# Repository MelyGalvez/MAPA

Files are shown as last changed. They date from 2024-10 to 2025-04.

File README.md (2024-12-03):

# MAPA
Module d'Apprentissage du Piano Automatisé (MAPA)

# Table des matières
1. Equipe de travail
2. Description du projet
3. Journal de bord

# 1. Equipe de travail

Software: Mely & Marin

Hardware: Justine & Jiajing

# 2. Description du projet
# 3. Journal de bord

## Première session 17 septembre 2024

Mise en place du projet MAPA. Brainstorming sur les différents point du sujet MAPA. Conception du diagramme fonctionnel du projet.

<div align="center">
  Schéma des étapes du projet
</div>
<div align="center">
Schéma des étapes du projet
</div>

<div align="center">
  Diagramme fonctionnel primitif
</div>
<div align="center">
Diagramme fonctionnel primitif
</div>

## Deuxième session 24 septembre 2024
Software: début de recherche de code pour traiter un fichier MIDI grâce à la STM32. Aussi recherche de code pour traiter un fichier audio (.wav)

Hardware: recherche des références des composants
## Troisième session 01 octobre 2024
Software: Avancement et réglage des erreurs du code de la semaine dernière

Hardware: Listes des références presque fini pour commander. Emprunt d'une petite bande LED à Mme.Kittel pour tester un code

## Quatrième session 8 octobre 2024

Présentation de l'avancement du projet

Software: Tuto en cours de compréhension, bibliothèque CMSIS installé. Code de control de Led avancé

Hardware: phase final des listes de références, régulateur, ruban led. Classification des composants dans des excels différent selon les contructeur pour commander

## Cinquième session 22 octobre 2024


## Sixième session 05 novembre 2024
Chez pas
## Septième session 12 novembre 2024

Code pour l'initialisation du ruban led avec 3 boutons

## Huitième session 19 novembre 2024

Mesure des touches du piano pour connaitre le ruban led ou  matrice de led à prendre

## Neuvième session 26 novembre 2024

Décision finale pour le choix de ruban led 

## Dixième session 03 décembre 2024
Mise en forme

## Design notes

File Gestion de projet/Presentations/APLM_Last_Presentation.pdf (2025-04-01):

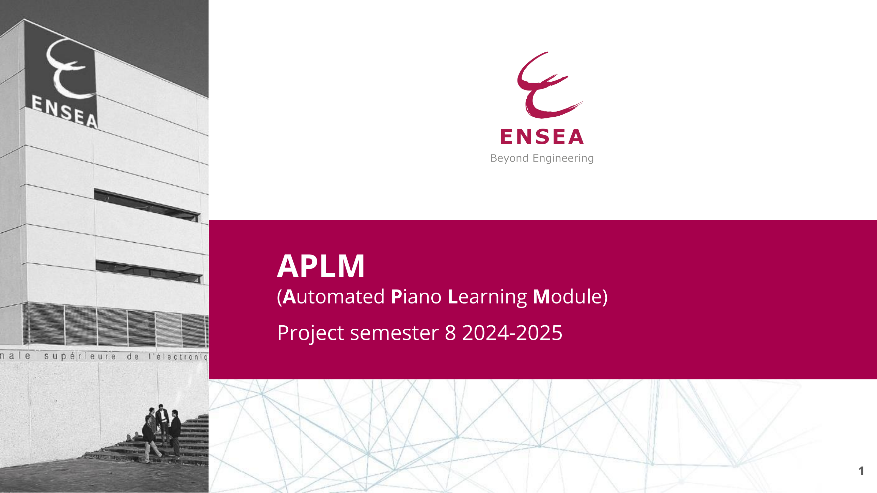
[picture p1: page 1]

# APLM

## (Automated Piano Learning Module)

## Project semester 8 2024-2025

1

# Contents

# I. Reminder and brief presentation of the project

# II. Demonstration

# III. Additional schematic and PCB Design

# IV. Digital audio signal processing

2

## I. Reminder and brief presentation of the project

# I. Reminder and brief presentation of the project

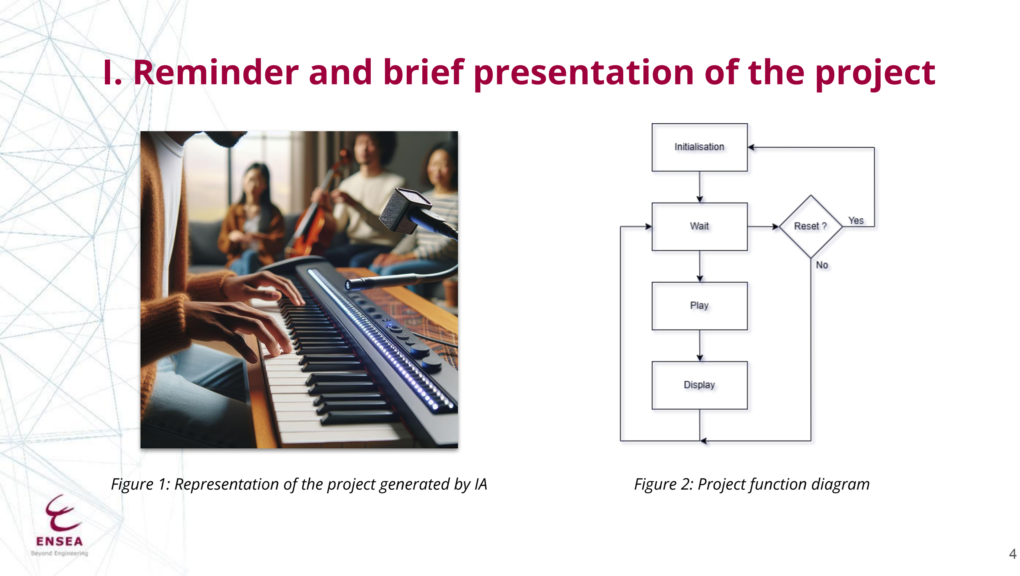
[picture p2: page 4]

Figure 1: Representation of the project generated by IA

Figure 2: Project function diagram

# I. Reminder and brief presentation of the project

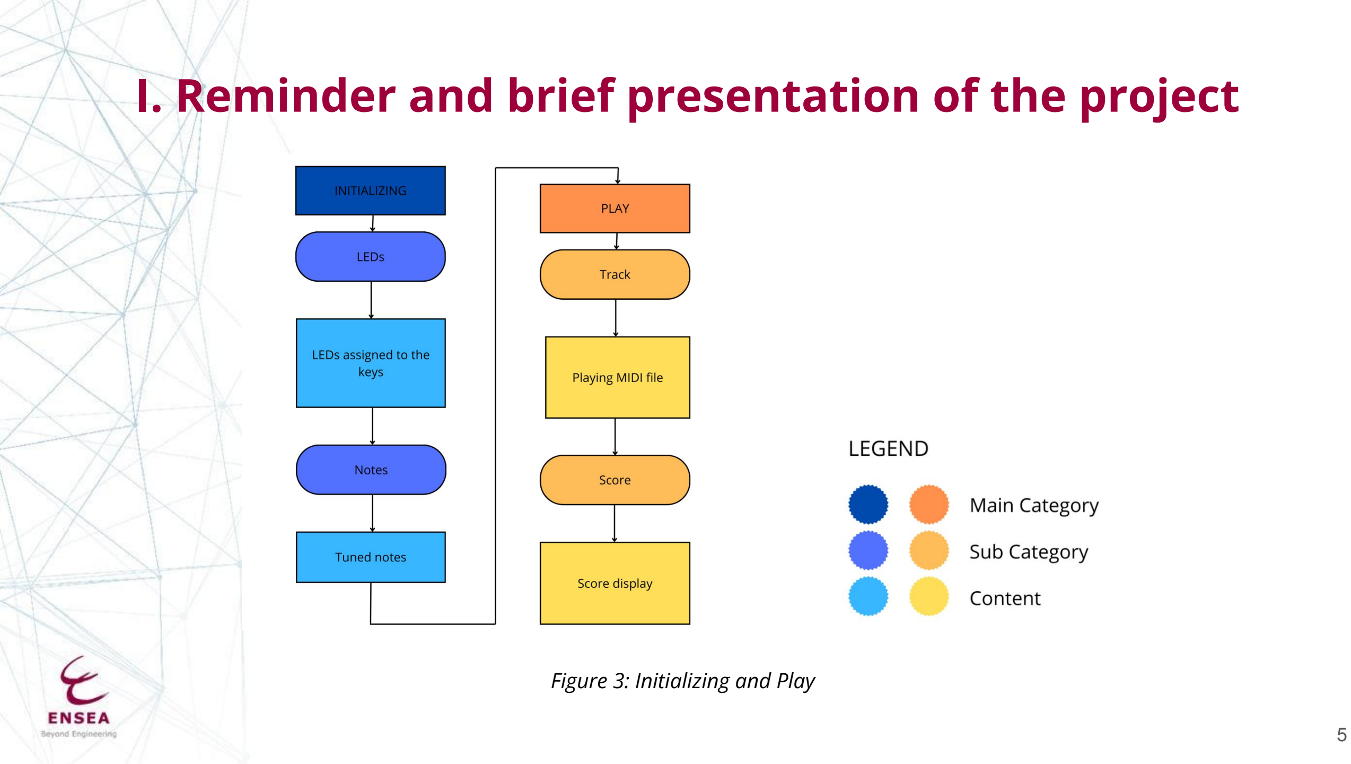
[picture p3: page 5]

Figure 3: Initializing and Play

## II. Demonstration

# II. Demonstration

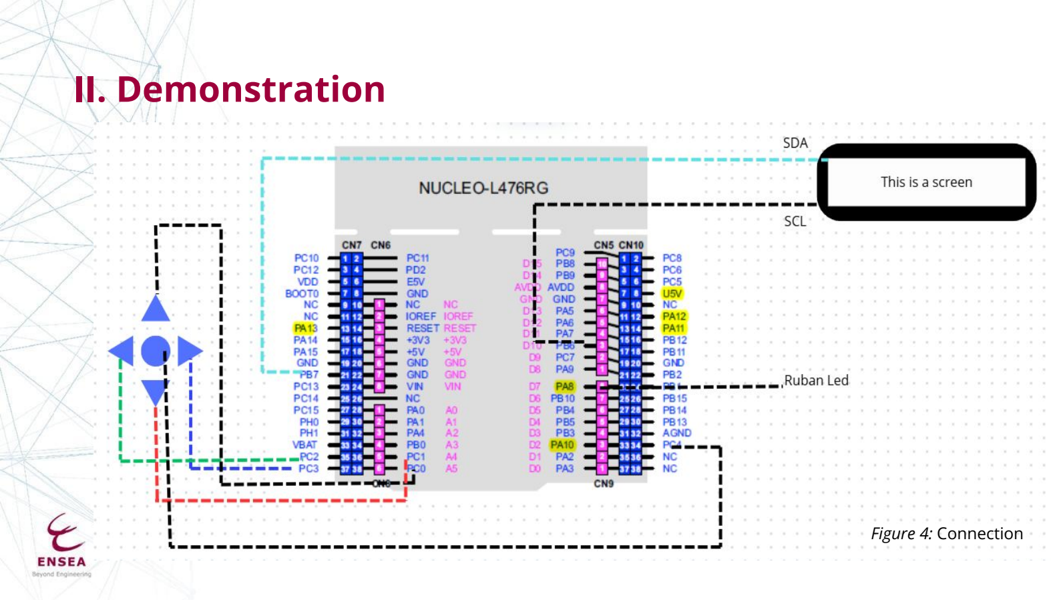
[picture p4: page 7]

Figure 4: Connection

# 1) Initialization

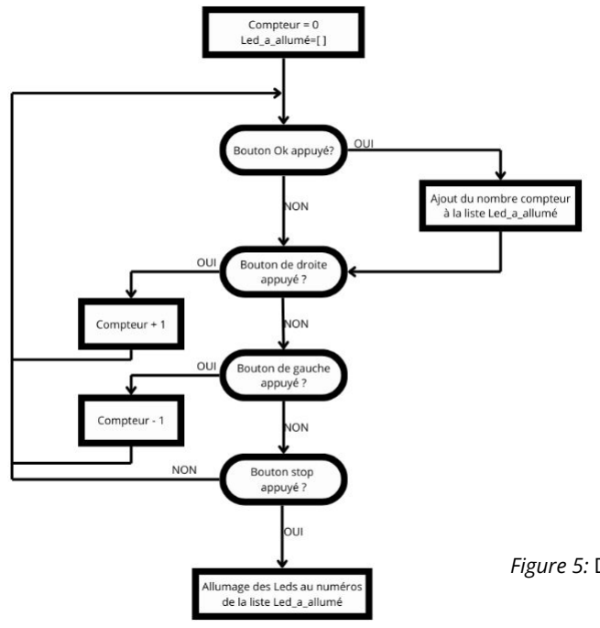
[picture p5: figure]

Figure 5: Decision diagram of Led assign

# 2) Menu

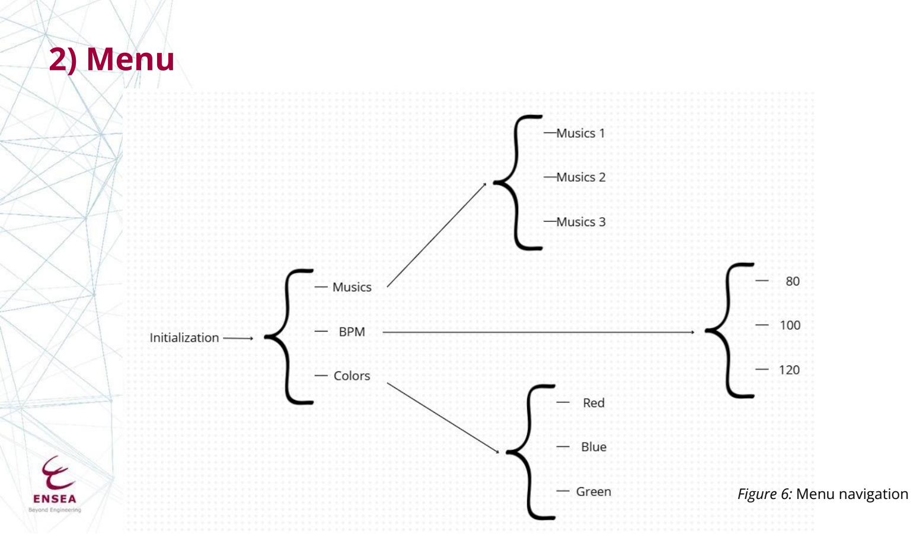
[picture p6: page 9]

Figure 6: Menu navigation

# 3) Possible Ameliorations

- Do the test for an entire piano and not just an octave
- Store more MIDI file in a SD card to play different music
- Increase the number of floors
- Complete the User Interface and functionality (Colors,BPM,...)
- Correct the initialization list with the real list played when there are several floors

## III. Additional schematic and PCB Design

# III. Additional schematic and PCB Design

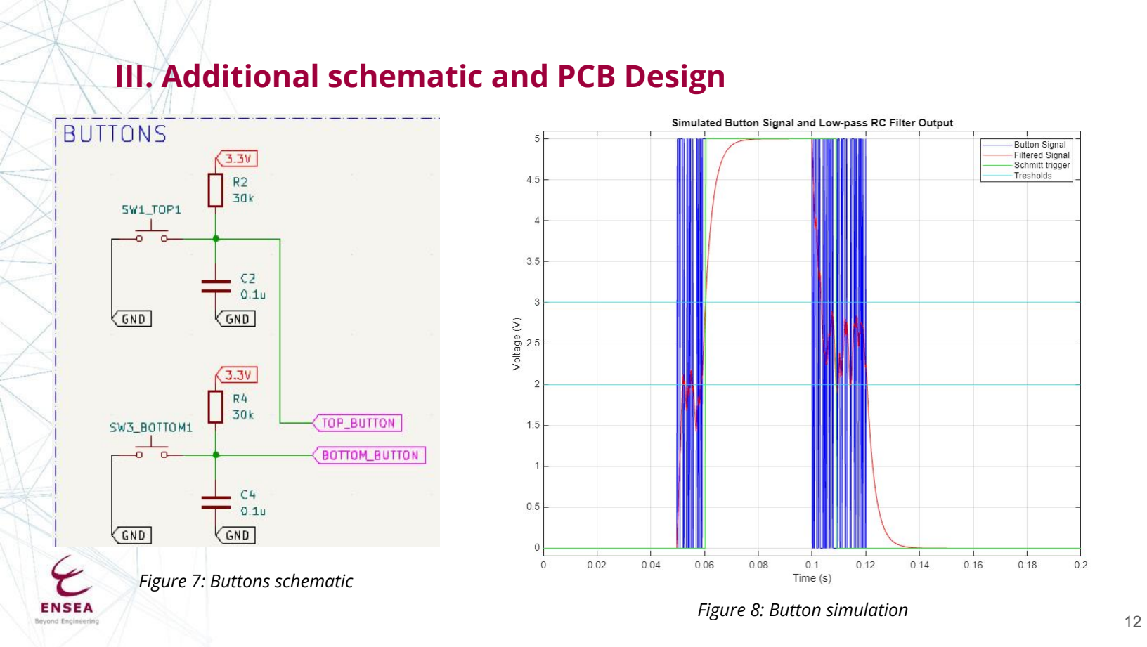
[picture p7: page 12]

Figure 7: Buttons schematic Figure 8: Button simulation

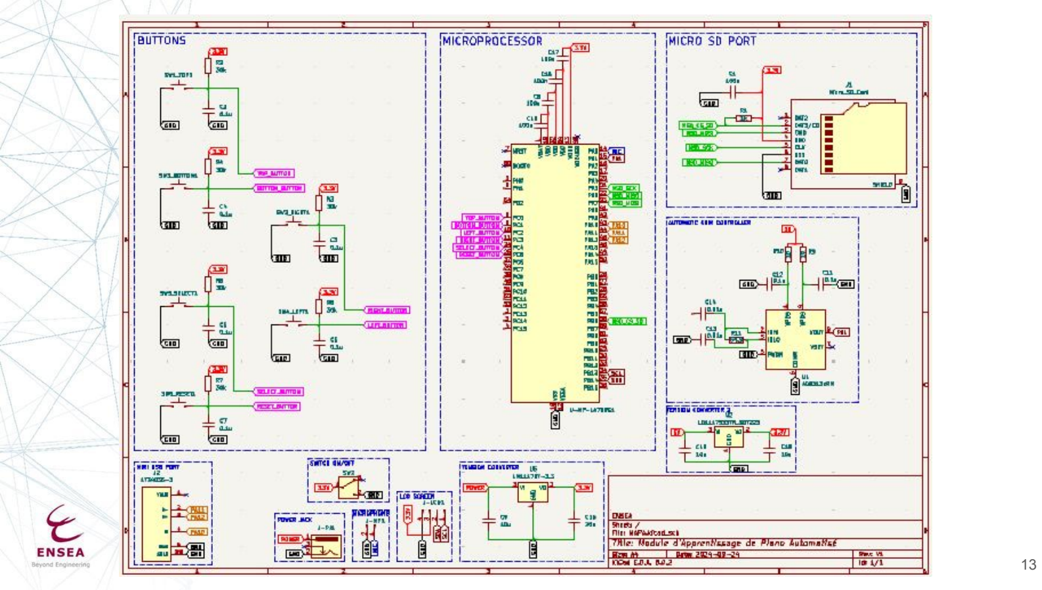
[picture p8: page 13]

# III. Additional schematic and PCB Design

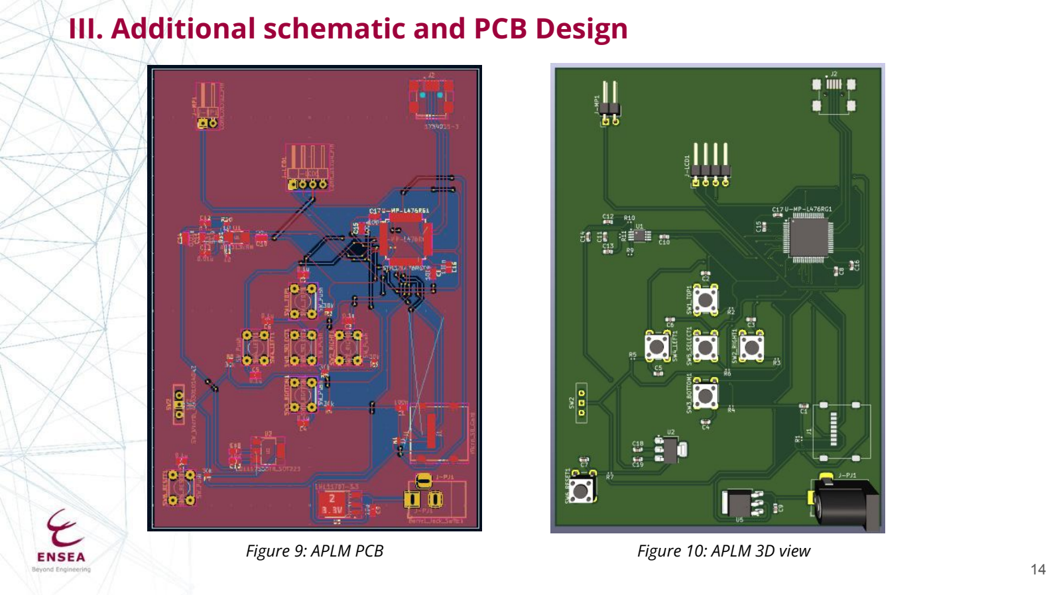
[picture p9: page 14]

Figure 9: APLM PCB

Figure 10: APLM 3D view

# III. Additional schematic and PCB Design

What's left to do as of today :

- Fix the issue with certain components on the PCB
- Print the PCB
- Solder the components onto the board

## IV. Digital audio signal processing

# IV. Digital audio signal processing

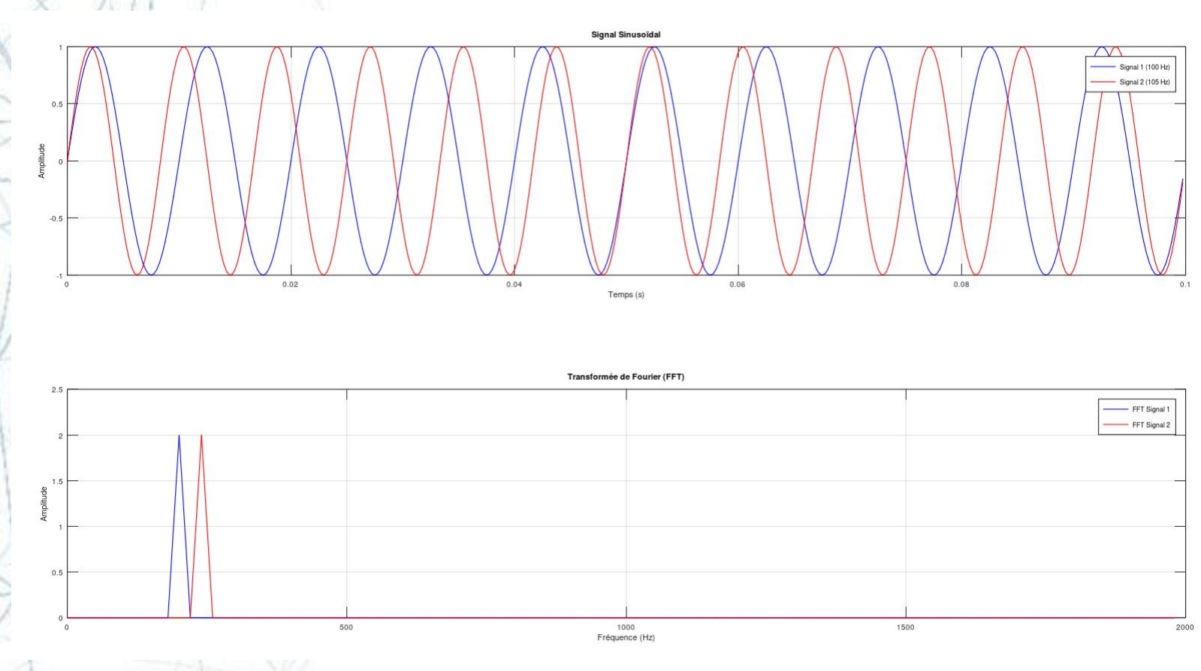
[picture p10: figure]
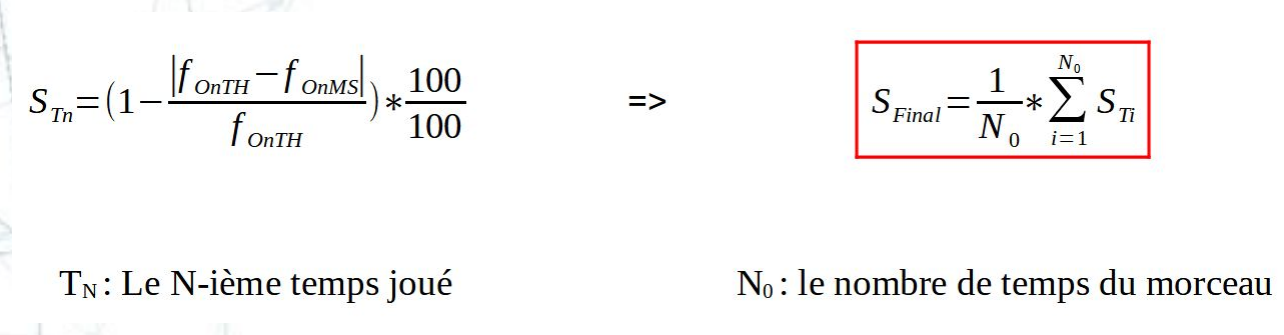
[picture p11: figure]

Figure 11: Method for evaluating the user score

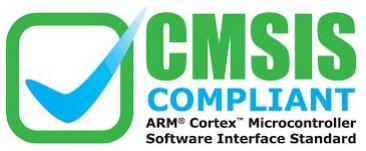
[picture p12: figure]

Figure 12: Useful libraries for the project

# V. Digital audio signal processing

# Solutions

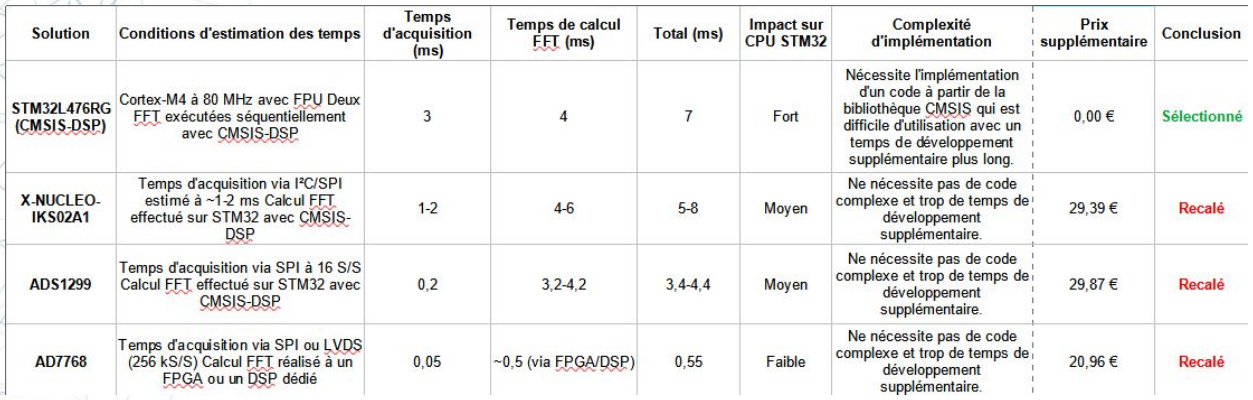
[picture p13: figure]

Figure 13: Options in numbers

# V. Digital audio signal processing

# Paradigm shift

# When initialising, record every FFT of every note on the piano!

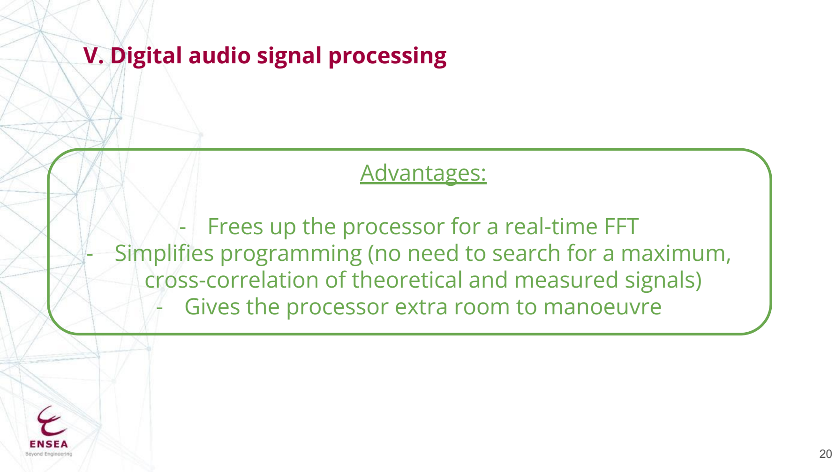
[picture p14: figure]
V. Digital audio signal processing; Advantages:

# - Frees up the processor for a real-time FFT

- Simplifies programming (no need to search for a maximum,

# cross-correlation of theoretical and measured signals) - Gives the processor extra room to manoeuvre

# V. Digital audio signal processing

# Physical simulation of the new process

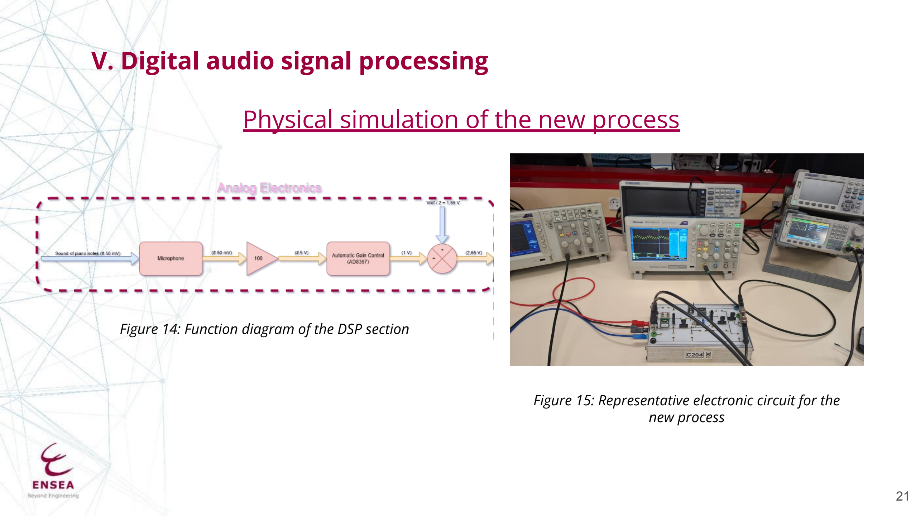
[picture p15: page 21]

Figure 15: Representative electronic circuit for the new process

Figure 14: Function diagram of the DSP section

# V. Digital audio signal processing

# Physical simulation of the new process

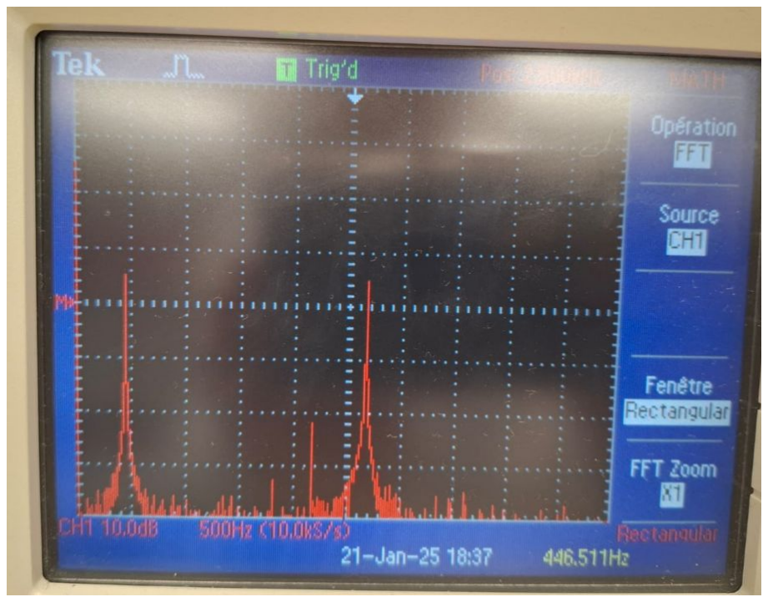
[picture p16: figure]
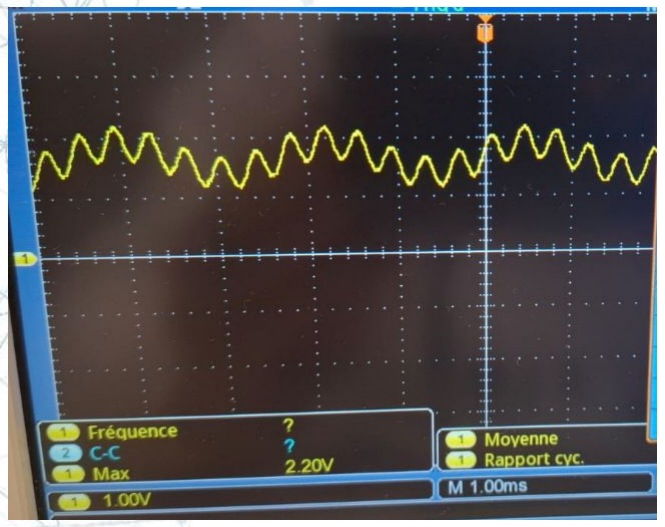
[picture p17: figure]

Figure 17: FFT of the sum Figure 16: Sum of signals

# V. Digital audio signal processing

# Introduction of white noise

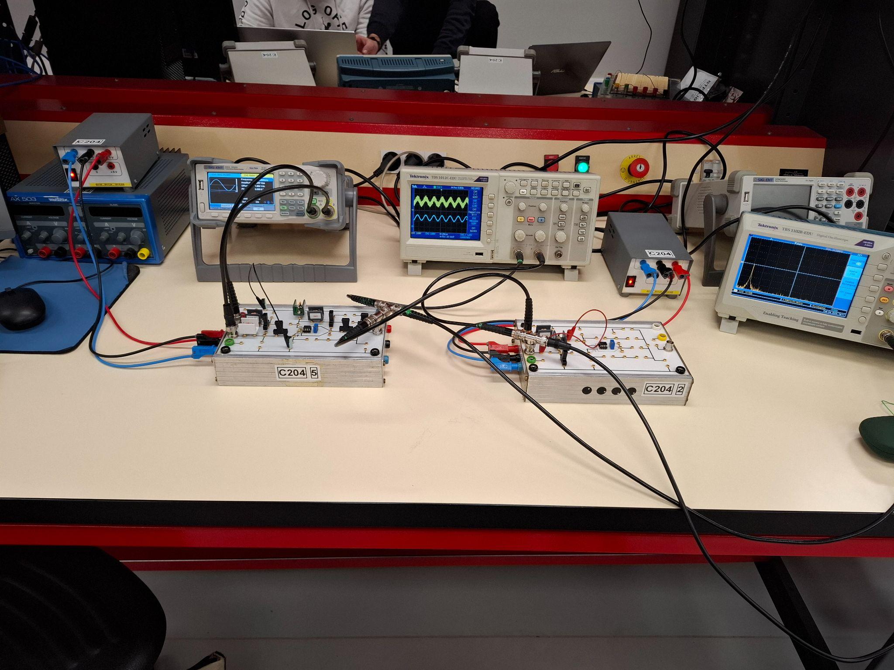
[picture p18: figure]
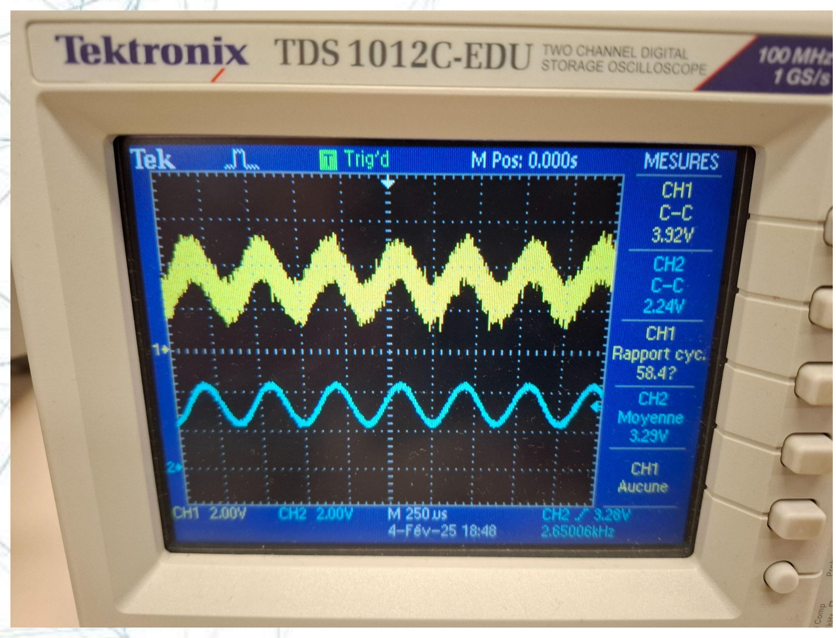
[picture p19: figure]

Figure 19: Electrical installation Figure 18: Noisy and filtered signal

# V. Digital audio signal processing

# Averaging filter

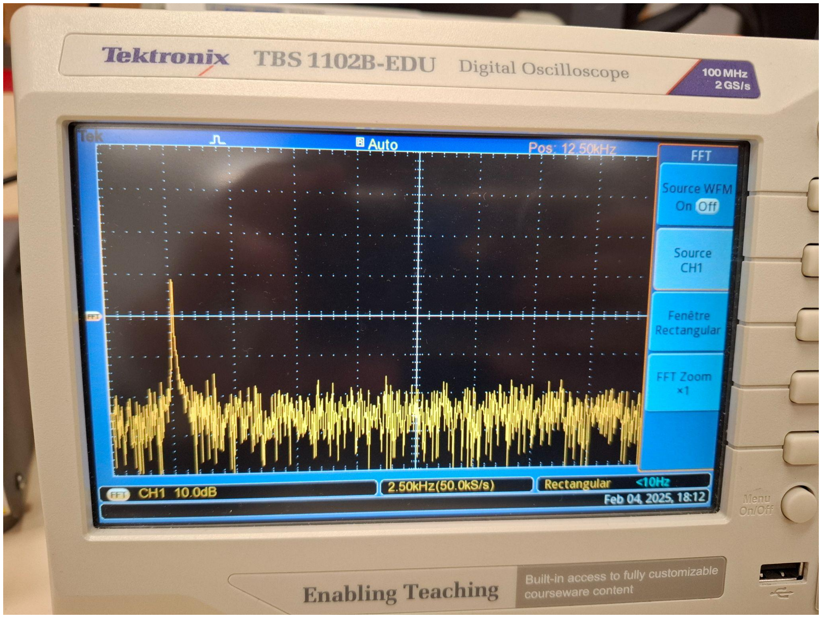
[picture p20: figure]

Figure 20: Filtered FFT

# V. Digital audio signal processing

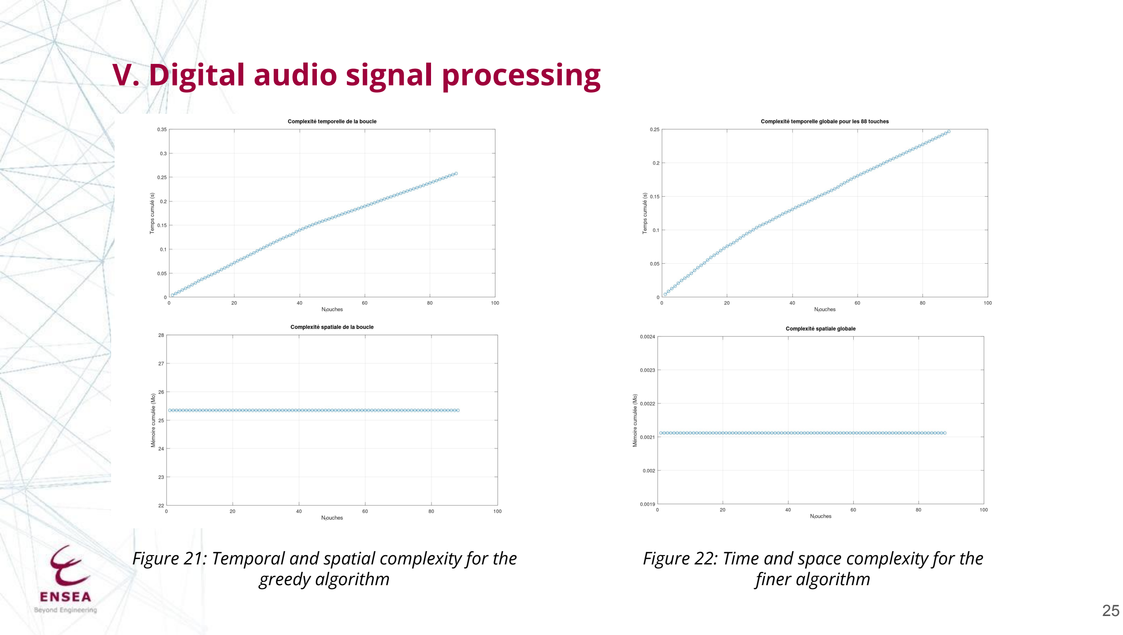
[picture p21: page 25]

Figure 22: Time and space complexity for the finer algorithm

Figure 21: Temporal and spatial complexity for the greedy algorithm

# V. Digital audio signal processing

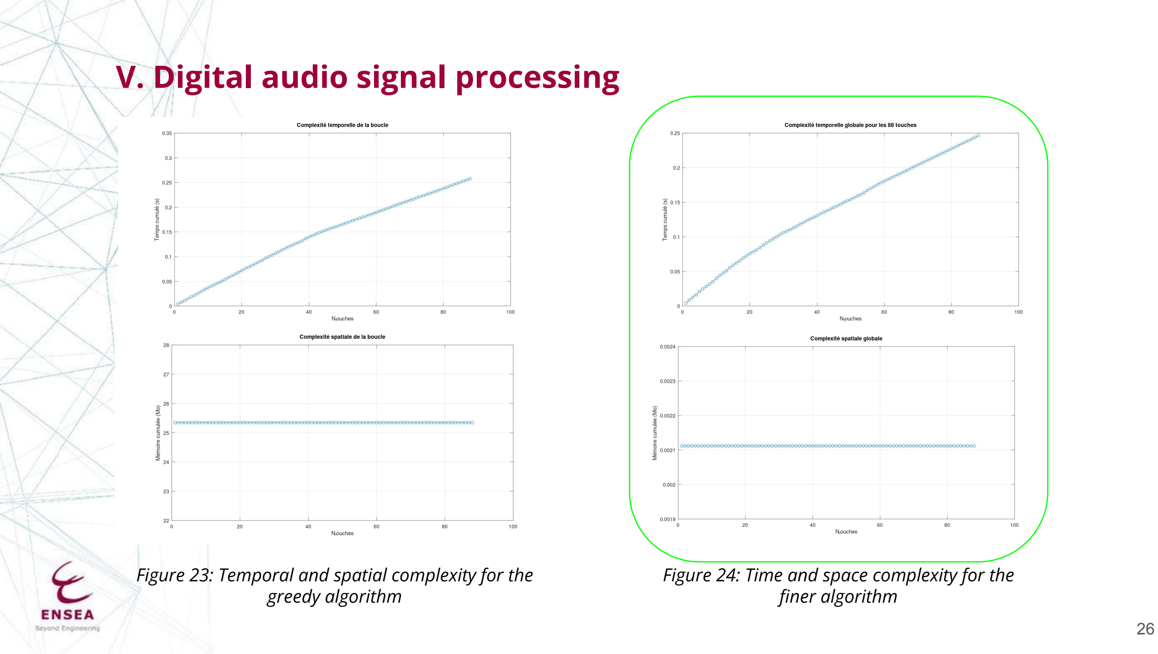
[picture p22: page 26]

Figure 24: Time and space complexity for the finer algorithm

Figure 23: Temporal and spatial complexity for the greedy algorithm

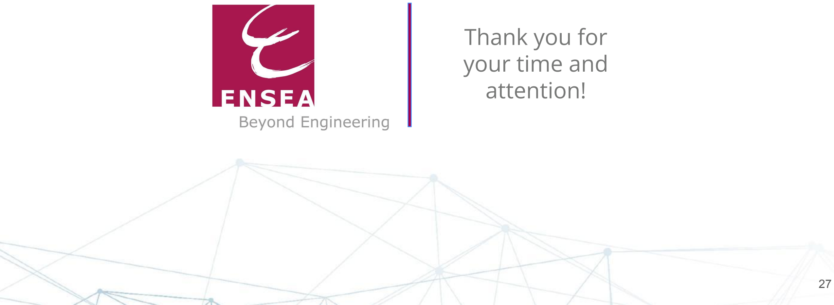
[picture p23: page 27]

# Thank you for your time and attention!

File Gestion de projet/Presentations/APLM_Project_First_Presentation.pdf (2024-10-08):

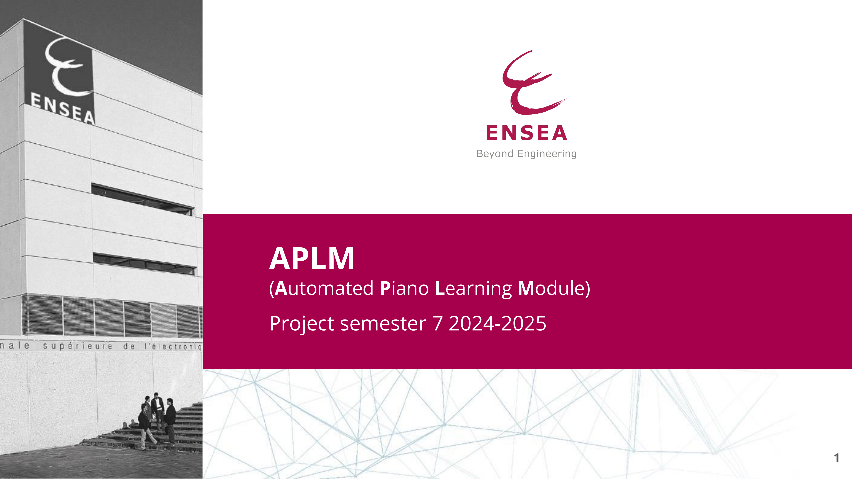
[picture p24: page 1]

# APLM

(Automated Piano Learning Module) Project semester 7 2024-2025

1

## Contents

I. Project Selection and Definition

II. Distribution of Roles

III. Component Search and Order

IV. Schematic and PCB Design

V. Processing a MIDI file

VI. Digital audio signal processing

2

I. Project Selection and Definition

3

## I. Project Selection and Definition


Figure 1: General outline of the project | Figure 2: LED ARGB strip

II. Distribution of Roles

Justine Hazan: PCB, Component research and control

Mély Galvez : Audio signal processing code

Jiajing Li: PCB, component research and control

Marin Kerboriou: MIDI file processing code

## II. Distribution of Roles

Emna Othmani

III. Component Search and Order

III. Component Search and Order

Figure 3: Main components and their place

Figure 4: Microprocessor; III. Component Search and Order; Purpose of the component:; ● Order the PCB components

Figure 5: SD card port; III. Component Search and Order; Purpose of the component:; ● Store data

Figure 6: AC/DC adapter; III. Component Search and Order; Purpose of the component:; Figure 7: Power Jack DC

- To have the correct alimentation for the PCB

Figure 8: interface; III. Component Search and Order; Purpose of the component:; ● Displays information

Figure 9: micro; III. Component Search and Order; Purpose of the component:; ● Captures sound

Figure 10: Led ARGB; III. Component Search and Order; Purpose of the component:

- Shows the note when they should be played

IV. Schematic and PCB Design

Figure 10: KiCad schematic

## V. Conception du Schéma et du PCB

INCOMING!

V. Processing a MIDI file

## VI. Processing a MIDI file


Figure 11: Outline for processing a MIDI file

## VI. Processing a MIDI file


Figure 12: Connexion
STM32 with LED strip

VI. Digital audio signal processing

## VI. Digital audio signal processing


Figure 13: Method for evaluating the user score


## VI. Digital audio signal processing


Figure 14: How CMSIS works | Figure 15: Code

## VI. Digital audio signal processing

Problems encountered:

- importing the library
- inclusion problems

Possible solutions:

- follow an online step-by-step method for importing


### Thank you for your time and attention!

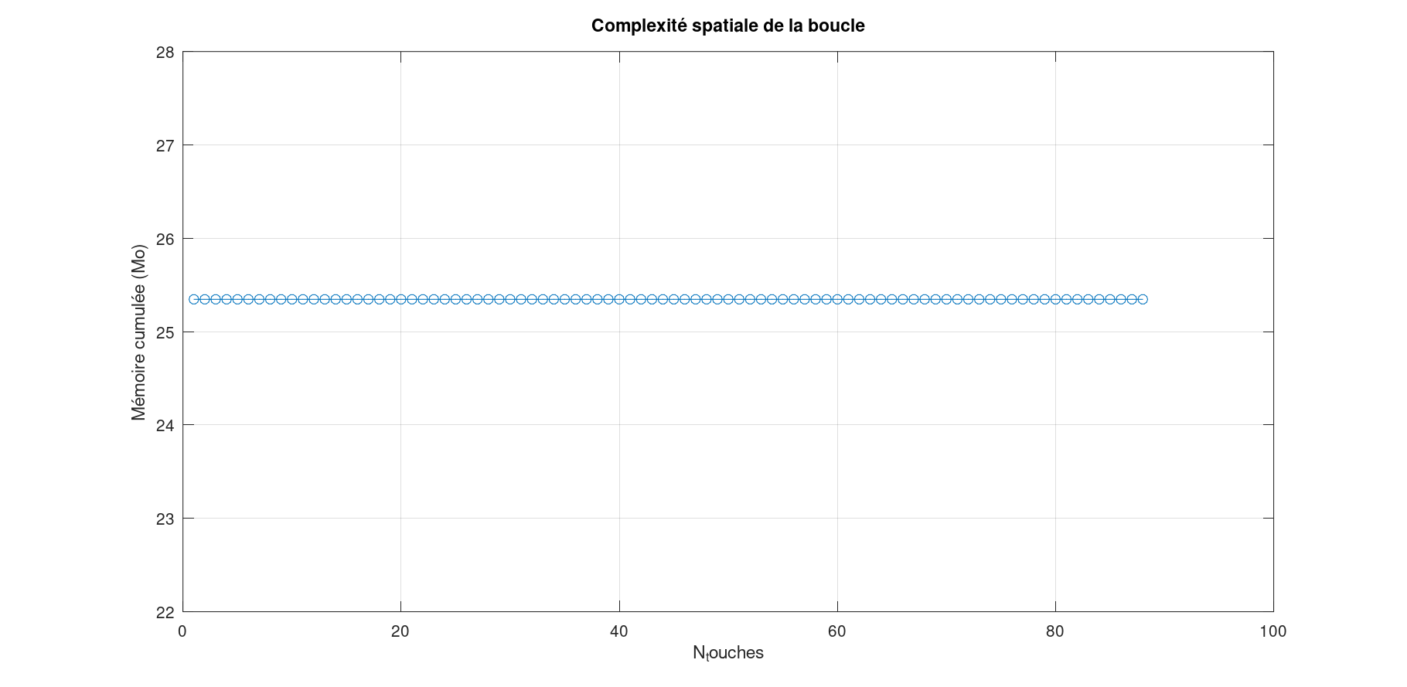
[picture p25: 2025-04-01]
Traitement numérique du signal du micro/Etude des complexités spatiales et temporelles/Résultats/Complexite_Spatiale_Glouton.png

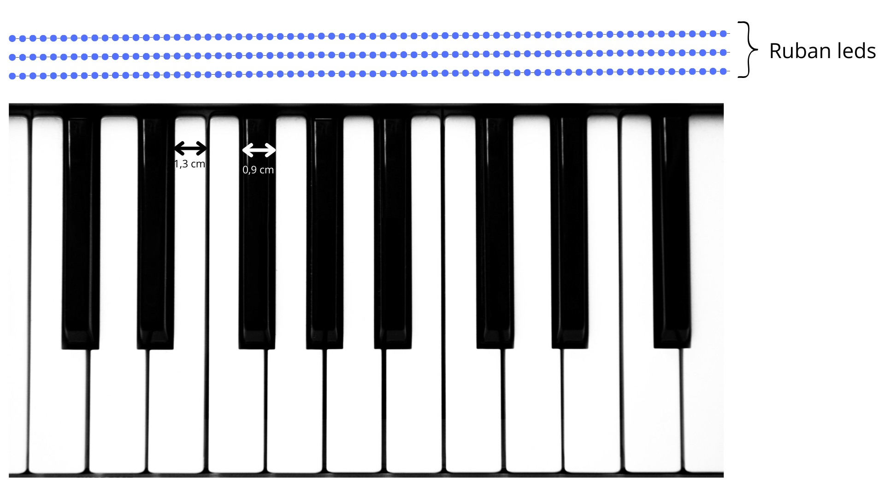
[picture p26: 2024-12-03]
Gestion de projet/Initialisation/Schéma piano avec ruban led.png

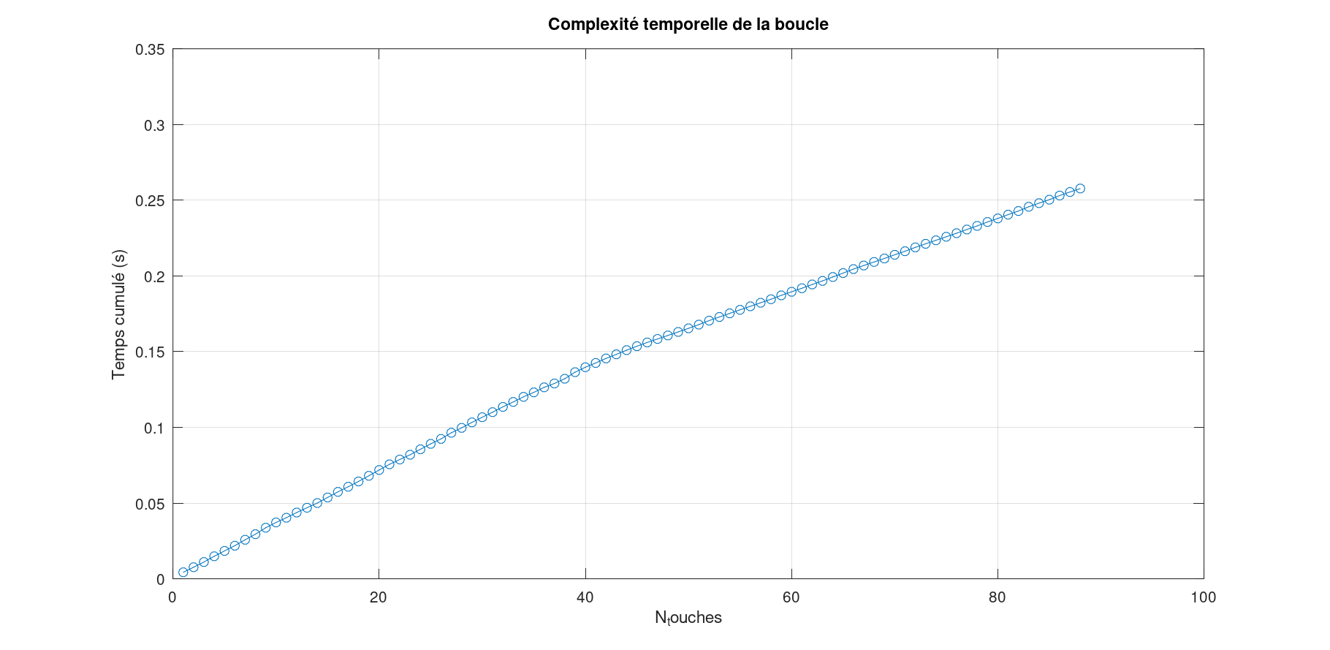
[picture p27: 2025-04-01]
Traitement numérique du signal du micro/Etude des complexités spatiales et temporelles/Résultats/Complexite_Temporelle_Glouton.png

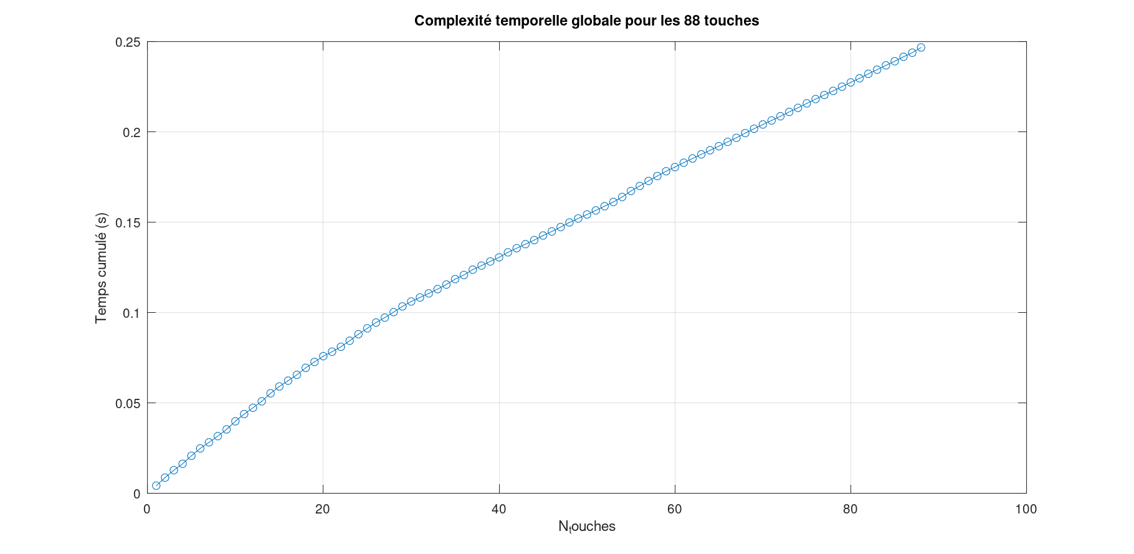
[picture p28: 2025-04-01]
Traitement numérique du signal du micro/Etude des complexités spatiales et temporelles/Résultats/Complexite_Temporelle_Fin.png

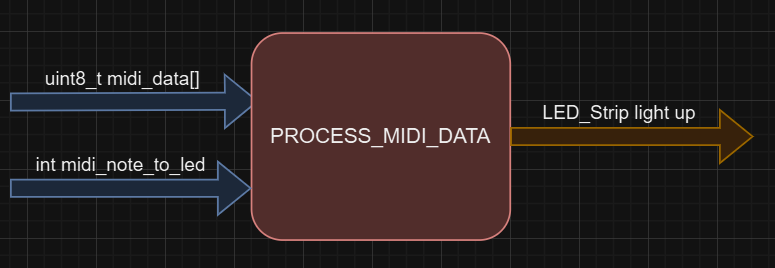
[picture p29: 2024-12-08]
Gestion de projet/Traitement fichier MIDI/MIDI_data/MIDI_data.png

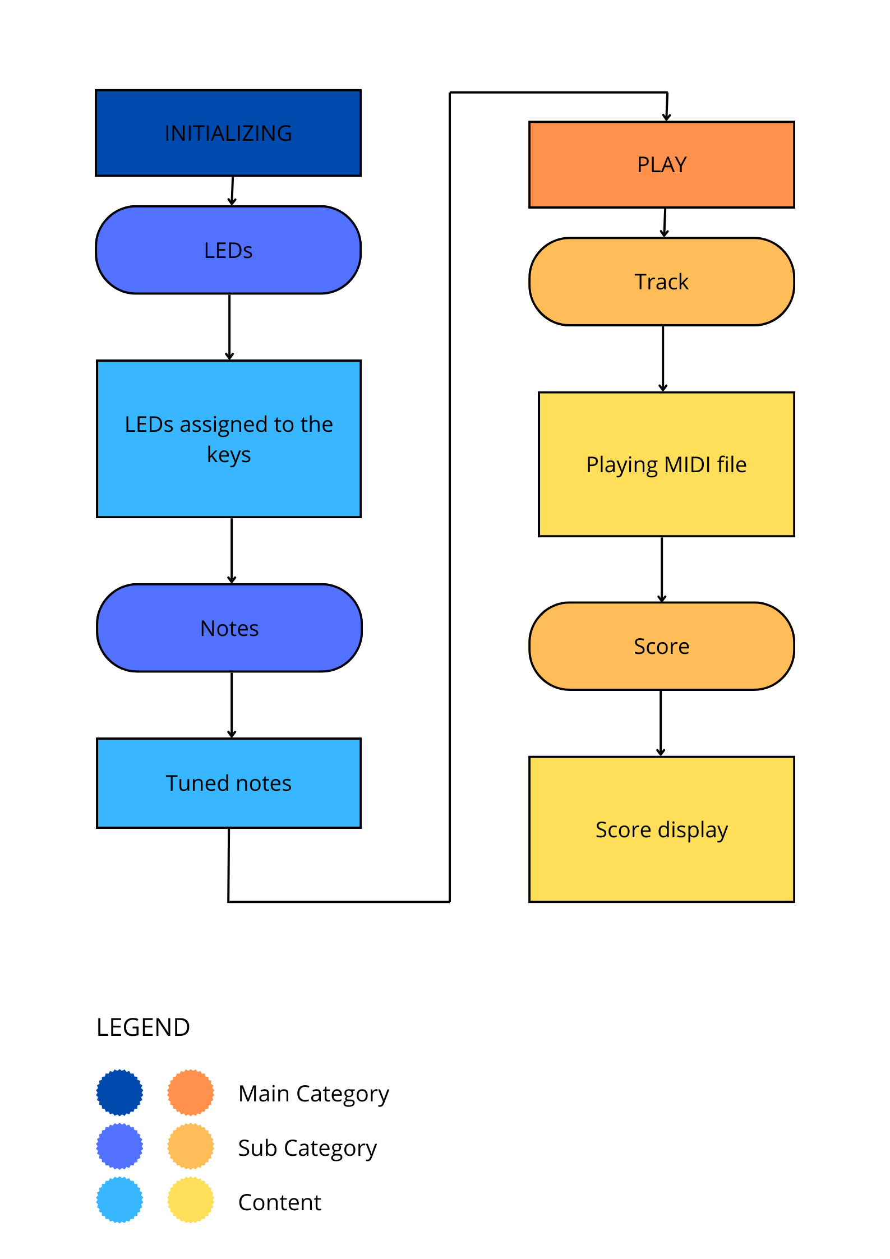
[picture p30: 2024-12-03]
Gestion de projet/Initialisation/Initialization & Play.png

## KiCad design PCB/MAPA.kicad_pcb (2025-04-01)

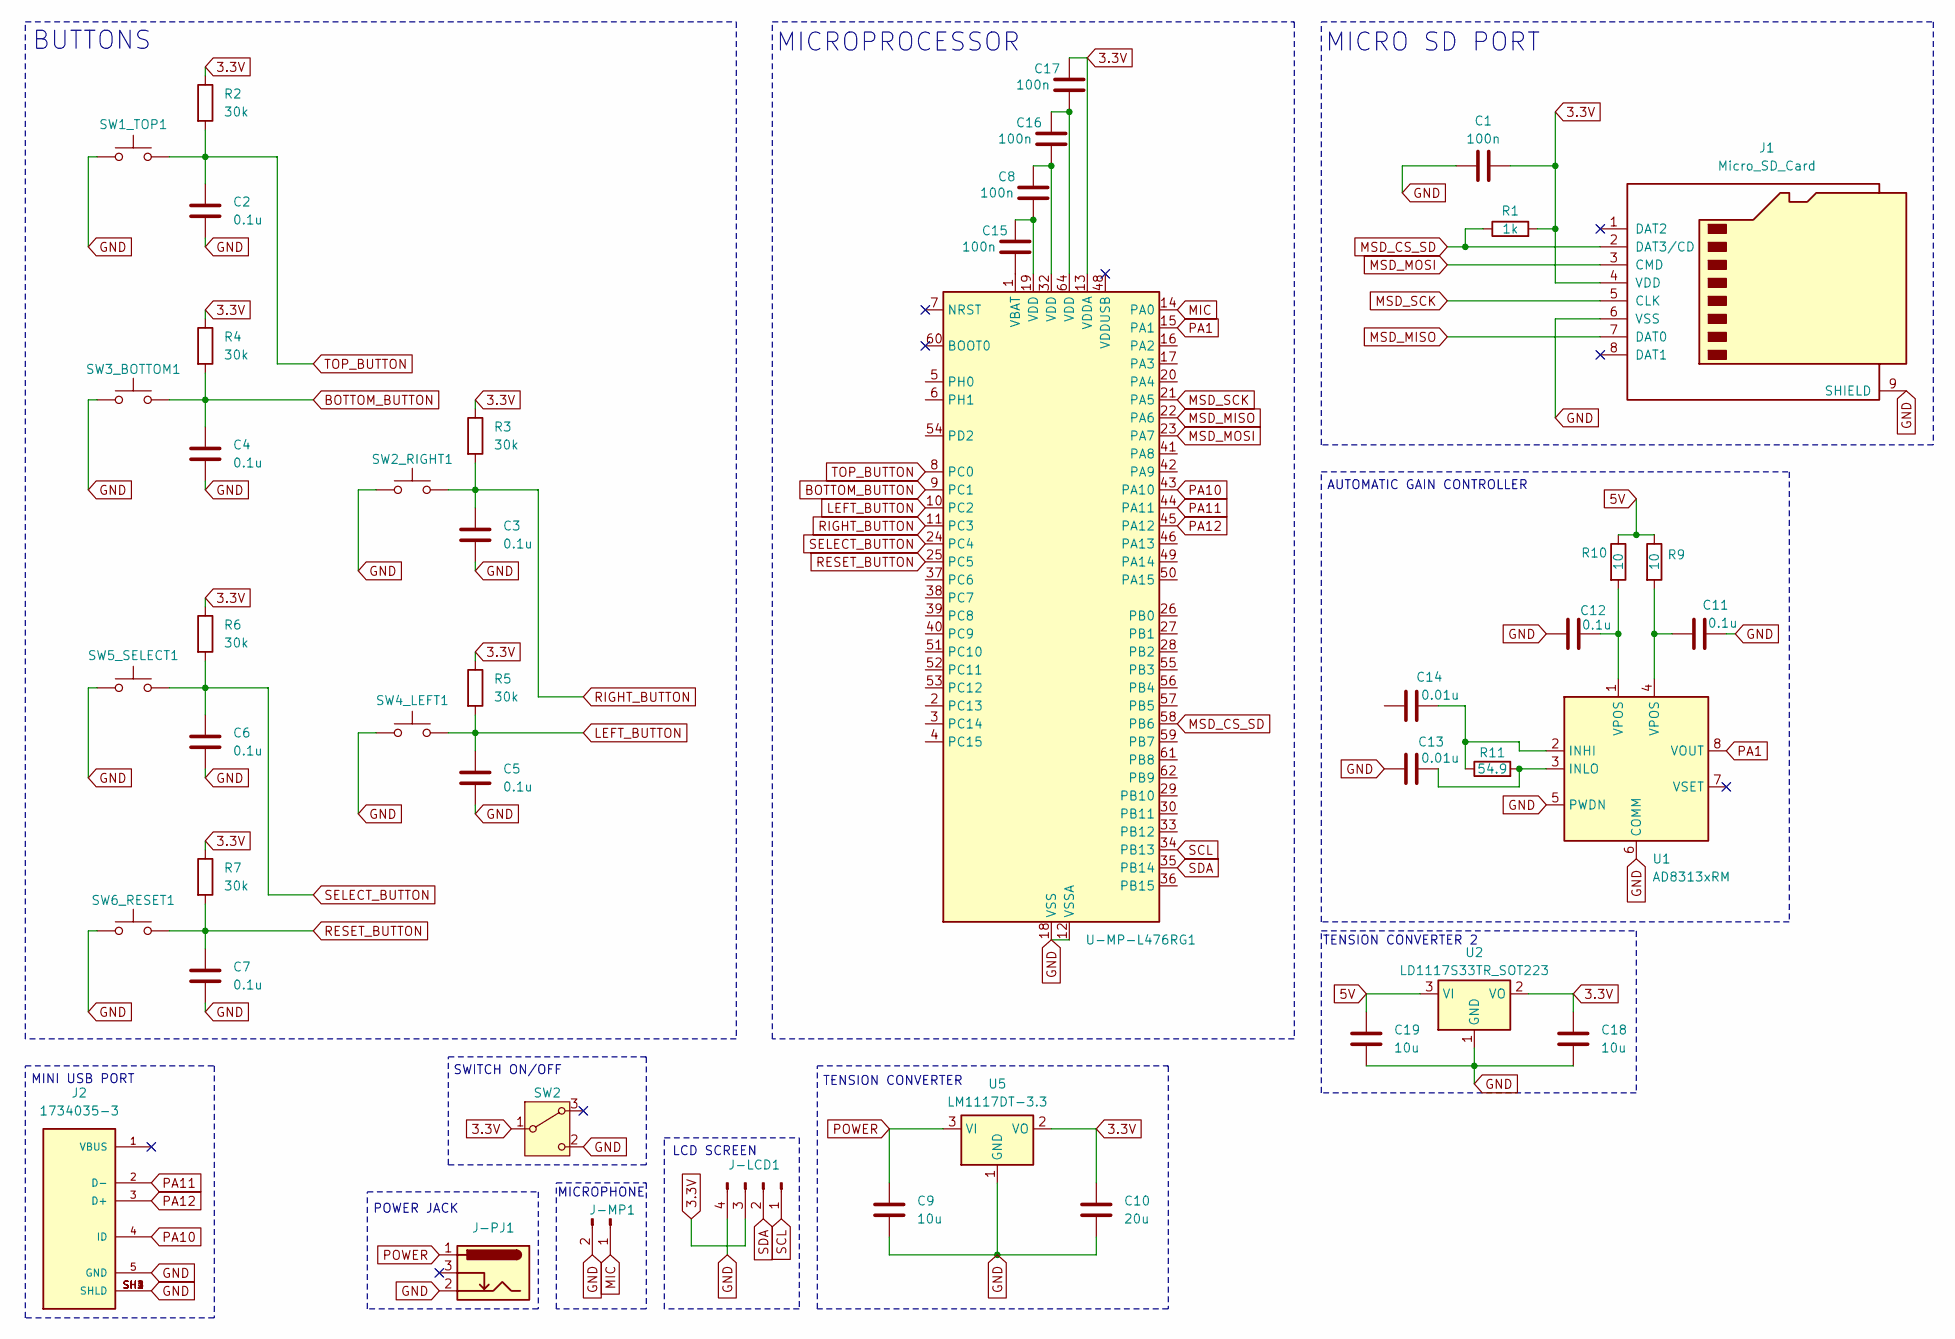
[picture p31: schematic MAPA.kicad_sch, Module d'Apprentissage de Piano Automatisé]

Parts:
C1, C8, C15, C16, C17: 100n; C_0603_1608Metric
C2, C3, C4, C5, C6, C7, C11, C12: 0.1u; C_0603_1608Metric
C9, C18, C19: 10u; C_0603_1608Metric
C10: 20u; C_0603_1608Metric
C13, C14: 0.01u; C_0603_1608Metric
J1: Micro_SD_Card; microSD_HC_Molex_47219-2001
J2: 1734035-3; TE_1734035-3; PARTREV F
J-LCD1: Conn_01x04_Pin; PinHeader_1x04_P2.54mm_Horizontal
J-MP1: Conn_01x02_Pin; PinHeader_1x02_P2.54mm_Horizontal
J-PJ1: Barrel_Jack_Switch; BarrelJack_Horizontal
R1: 1k; R_0201_0603Metric
R2, R3, R4, R5, R6, R7: 30k; R_0201_0603Metric
R9, R10: 10; R_0201_0603Metric
R11: 54.9; R_0201_0603Metric
SW1_TOP1, SW2_RIGHT1, SW3_BOTTOM1, SW4_LEFT1, SW5_SELECT1, SW6_RESET1: SW_Push; SW_PUSH_6mm
SW2: SW_Wuerth_450301014042; SW_Slide-03_Wuerth-WS-SLTV_10x2.5x6.4_P2.54mm
U1: AD8313xRM; MSOP-8_3x3mm_P0.65mm
U2: LD1117S33TR_SOT223; SOT-223-3_TabPin2
U5: LM1117DT-3.3; TO-252-3_TabPin2
U-MP-L476RG1: STM32L476RGTx; LQFP-64_10x10mm_P0.5mm

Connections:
3.3V: C1.2, C10.1, C17.1, C18.1, J1.4 (VDD), J-LCD1.3, R1.2, R2.1, R3.1, R4.1, R5.1, R6.1, R7.1, SW2.1 (B), U2.2 (VO), U5.2 (VO), U-MP-L476RG1.13 (VDDA)
5V: C19.1, R9.1, R10.1, U2.3 (VI)
BOTTOM_BUTTON: C4.1, R4.2, SW3_BOTTOM1.2, U-MP-L476RG1.9 (PC1)
GND: C1.1, C2.2, C3.2, C4.2, C5.2, C6.2, C7.2, C9.2, C10.2, C11.2, C12.1, C13.1, C18.2, C19.2, J1.6 (VSS), J1.9 (SHIELD), J2.5 (GND), J2.SH1 (SHLD), J2.SH2 (SHLD), J2.SH3 (SHLD), J2.SH4 (SHLD), J-LCD1.4, J-MP1.2, J-PJ1.2, SW1_TOP1.1, SW2.2 (C), SW2_RIGHT1.1, SW3_BOTTOM1.1, SW4_LEFT1.1, SW5_SELECT1.1, SW6_RESET1.1, U1.5 (PWDN), U1.6 (COMM), U2.1 (GND), U5.1 (GND), U-MP-L476RG1.12 (VSSA), U-MP-L476RG1.18 (VSS), U-MP-L476RG1.31 (VSS), U-MP-L476RG1.47 (VSS), U-MP-L476RG1.63 (VSS)
LEFT_BUTTON: C5.1, R5.2, SW4_LEFT1.2, U-MP-L476RG1.10 (PC2)
MIC: J-MP1.1, U-MP-L476RG1.14 (PA0)
MSD_CS_SD: J1.2 (DAT3/CD), R1.1, U-MP-L476RG1.58 (PB6)
MSD_MISO: J1.7 (DAT0), U-MP-L476RG1.22 (PA6)
MSD_MOSI: J1.3 (CMD), U-MP-L476RG1.23 (PA7)
MSD_SCK: J1.5 (CLK), U-MP-L476RG1.21 (PA5)
unnamed: C11.1, R9.2, U1.4 (VPOS)
unnamed: C12.2, R10.2, U1.1 (VPOS)
unnamed: C8.2, C15.1, U-MP-L476RG1.19 (VDD)
unnamed: C16.1, C17.2, U-MP-L476RG1.64 (VDD)
unnamed: C8.1, C16.2, U-MP-L476RG1.32 (VDD)
unnamed: C14.2, R11.1, U1.2 (INHI)
unnamed: C13.2, R11.2, U1.3 (INLO)
unnamed: C15.2, U-MP-L476RG1.1 (VBAT)
PA1: U1.8 (VOUT), U-MP-L476RG1.15 (PA1)
PA10: J2.4 (ID), U-MP-L476RG1.43 (PA10)
PA11: J2.2 (D-), U-MP-L476RG1.44 (PA11)
PA12: J2.3 (D+), U-MP-L476RG1.45 (PA12)
POWER: C9.1, J-PJ1.1, U5.3 (VI)
RESET_BUTTON: C7.1, R7.2, SW6_RESET1.2, U-MP-L476RG1.25 (PC5)
RIGHT_BUTTON: C3.1, R3.2, SW2_RIGHT1.2, U-MP-L476RG1.11 (PC3)
SCL: J-LCD1.1, U-MP-L476RG1.34 (PB13)
SDA: J-LCD1.2, U-MP-L476RG1.35 (PB14)
SELECT_BUTTON: C6.1, R6.2, SW5_SELECT1.2, U-MP-L476RG1.24 (PC4)
TOP_BUTTON: C2.1, R2.2, SW1_TOP1.2, U-MP-L476RG1.8 (PC0)

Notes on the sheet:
TENSION CONVERTER 2
MICROPROCESSOR
SWITCH ON/OFF
LCD SCREEN
MINI USB PORT
TENSION CONVERTER
BUTTONS
MICROPHONE
AUTOMATIC GAIN CONTROLLER
POWER JACK
MICRO SD PORT

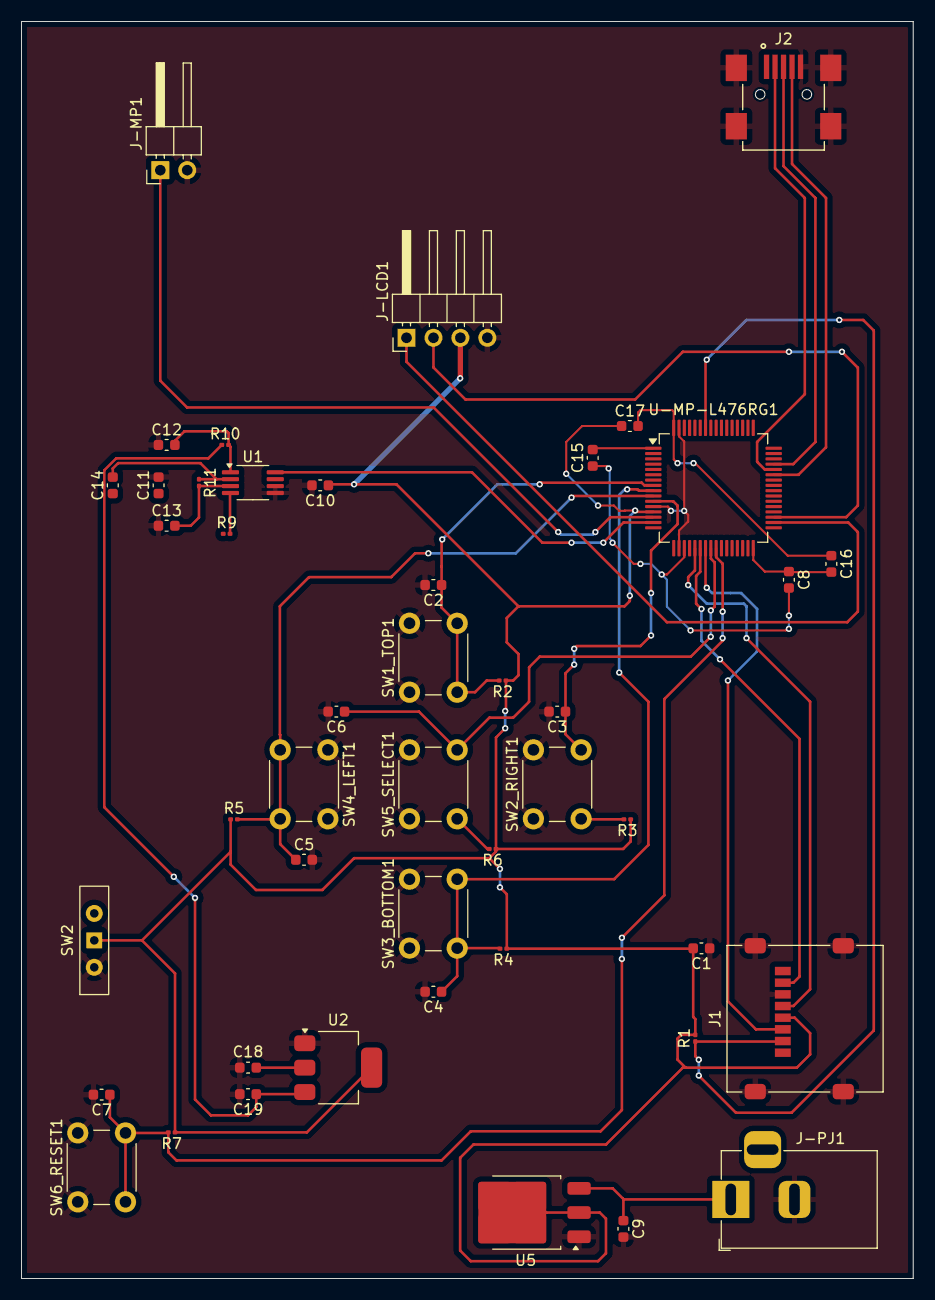
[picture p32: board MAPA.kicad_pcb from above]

Board: 2 copper layers, 84.1 x 118.5 mm, 45 parts (0 on the bottom side), 29 nets.

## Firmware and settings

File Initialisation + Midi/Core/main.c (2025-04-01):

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
/* Includes ------------------------------------------------------------------*/
#include "main.h"

/* USER CODE BEGIN Includes */
#include "stm32l4xx_hal.h"
#include "brillez.h"
#include "ecran.h"
#include "string.h"
#include <stdio.h>
#include "midi_parser.h"
#include "init.h"
/* USER CODE END Includes */

I2C_HandleTypeDef hi2c1;

TIM_HandleTypeDef htim1;
DMA_HandleTypeDef hdma_tim1_ch1;

UART_HandleTypeDef huart2;

/* USER CODE BEGIN PV */
int __io_putchar(int ch) {
    HAL_UART_Transmit(&huart2, (uint8_t *)&ch, 1, HAL_MAX_DELAY);
    return ch;
}

/* USER CODE END PV */

void SystemClock_Config(void);
static void MX_GPIO_Init(void);
static void MX_DMA_Init(void);
static void MX_USART2_UART_Init(void);
static void MX_TIM1_Init(void);
static void MX_I2C1_Init(void);
/**
  * @brief  The application entry point.
  * @retval int
  */
int main(void)
{

  /* MCU Configuration--------------------------------------------------------*/

  /* Reset of all peripherals, Initializes the Flash interface and the Systick. */
  HAL_Init();

  /* Configure the system clock */
  SystemClock_Config();

  /* Initialize all configured peripherals */
  MX_GPIO_Init();
  MX_DMA_Init();
  MX_USART2_UART_Init();
  MX_TIM1_Init();
  MX_I2C1_Init();
  /* USER CODE BEGIN 2 */
  brillez_init();


  LCD_Init();
  LCD_Clear();

	LCD_SetRGB(40, 130, 255);  // Bleu


     // Boucle principale

  /* USER CODE END 2 */

  /* Infinite loop */
  /* USER CODE BEGIN WHILE */
	  assignement();
	  printf("fin assignement \r\n");

	  Navigation();


  while (1)
  {

/*			HAL_Delay(50);

	  		LCD_Clear();  // Efface l’écran avant d’écrire

	  		LCD_PrintFormatted("LED numero %lu", compteur);  // Affiche le compteur
	  		HAL_Delay(500);

	  		printf("Liste des sauvegardes : ");
	  		for (uint32_t i = 0; i < sauvegarde_index; i++) {
	  		  printf("%ld ", compteur_sauvegarde[i]);
	  		}
	  		printf("\r\n");

	  		light_up_led(compteur, 0xFF0000, 100);

	  		for (uint32_t i = 0; i < sauvegarde_index; i++) {
	  		  ws2812b_set_led_hex(&h_ws2812b,compteur_sauvegarde[i], 0x00FF00);
	  		}
*/

    /* USER CODE END WHILE */

    /* USER CODE BEGIN 3 */


  }
  /* USER CODE END 3 */
}

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


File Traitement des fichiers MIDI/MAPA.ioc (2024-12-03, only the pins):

Mcu.UserName=STM32L476RGTx
PA2.GPIO_Label=USART_TX
PA2.Signal=USART2_TX
PA3.GPIO_Label=USART_RX
PA3.Signal=USART2_RX
PA5.GPIO_Label=LD2 [green Led]
PA5.Signal=GPIO_Output
PA8.Signal=S_TIM1_CH1
PB10.Signal=SPI2_SCK
PC13.GPIO_Label=B1 [Blue PushButton]
PC13.Signal=GPXTI13
PC2.Signal=SPI2_MISO
PC3.Signal=SPI2_MOSI

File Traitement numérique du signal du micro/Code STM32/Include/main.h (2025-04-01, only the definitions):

#define AUDIO_BUFFER_SIZE 1024  // Define the buffer size for audio processing
#define SAMPLE_RATE 32000       // Define the sample rate
#define B1_Pin GPIO_PIN_13
#define B1_GPIO_Port GPIOC
#define B1_EXTI_IRQn EXTI15_10_IRQn
#define USART_TX_Pin GPIO_PIN_2
#define USART_TX_GPIO_Port GPIOA
#define USART_RX_Pin GPIO_PIN_3
#define USART_RX_GPIO_Port GPIOA
#define LD2_Pin GPIO_PIN_5
#define LD2_GPIO_Port GPIOA
#define TMS_Pin GPIO_PIN_13
#define TMS_GPIO_Port GPIOA
#define TCK_Pin GPIO_PIN_14
#define TCK_GPIO_Port GPIOA
#define SWO_Pin GPIO_PIN_3
#define SWO_GPIO_Port GPIOB

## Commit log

2024-10-01 Update README.md
    ajout dans #1 et dans tableau de bord
2024-12-03 Add files via upload
    Schéma explicatif de l'initialisation de mapa
2024-12-03 Add files via upload
    schéma sur le fonctionnement de l'initialisation de MAPA
2024-12-03 Update and rename main.c to main.c du code pour selectionner les led
2024-12-08 Rename Capture d'écran 2024-12-08 111644.png to LED_data.pnj

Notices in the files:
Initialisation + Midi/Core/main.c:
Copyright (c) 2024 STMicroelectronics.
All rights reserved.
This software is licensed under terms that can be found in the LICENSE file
